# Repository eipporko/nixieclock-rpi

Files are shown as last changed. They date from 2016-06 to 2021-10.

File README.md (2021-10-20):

"Buy Me A Coffee" (https://www.buymeacoffee.com/eipporko)

6 digit Nixie Clock
===================

## Motivation

* [Alex's Nixie Clock](https://www.raspberrypi.org/blog/alexs-nixie-clock/)

## Project structure

 * `hardware/eagle` - PCB design and schematics
 * `hardware/docs`  - various PDF datasheets for components used
 * `software`       - clock program

## BOM Summary
Main components

 * IN-8-2 Nixie tubes
 * MH74141 Nixie driver
 * 74HCT259 8-bit addressable latch
 * SN74LS77 4-bit D latch
 * ULN2803A Eight Darligton array
 * Raspberry Pi Zero, 1, 2 or 3 (Models B, B+)

The BCD decoder IC and Nixie tubes is hard to obtain, so far they're only
available on ebay and most of them are NOS(new old stock)

Check the schematics for the rest of the passives

## Theory of operation

### Architecture
Every digit of the display is composed by a Nixie tube (IN-8-2) driven by a
decimal decoder designed for directly drive this kind of gas-filled cold-cathode
indicators (MH74141) which input is supplied by a 4-bit D Latch (SN74LS77).

Each latch is multiplexed, with one 3-line to 8-line demux with latch (74HCT259),
in order to share the 4 bit bus with all the drivers.

In this way it's only needed 8 bits to control the clock's display.

```
** RPI GPIO HEADER SCHEMATIC **
                            .___.
                   +3V3---1-|O O|--2--+5V
           (SDA)  GPIO2---3-|O O|--4--+5V
          (SCL1)  GPIO3---5-|O O|--6--_
     (GPIO_GLCK)  GPIO4---7-|O O|--8-----GPIO14 (TXD0)
                       _--9-|O.O|-10-----GPIO15 (RXD0)
     (GPIO_GEN0) GPIO17--11-|O O|-12-----GPIO18 (GPIO_GEN1)
     (GPIO_GEN2) GPIO27--13-|O O|-14--_
     (GPIO_GEN3) GPIO22--15-|O O|-16-----GPIO23 (GPIO_GEN4)
                   +3V3--17-|O O|-18-----GPIO24 (GPIO_GEN5)
      (SPI_MOSI) GPIO10--19-|O.O|-20--_
      (SPI_MOSO) GPIO9 --21-|O O|-22-----GPIO25 (GPIO_GEN6)
      (SPI_SCLK) GPIO11--23-|O O|-24-----GPIO8  (SPI_C0_N)
                       _-25-|O O|-26-----GPIO7  (SPI_C1_N)
        (EEPROM) ID_SD---27-|O O|-28-----ID_SC Reserved for ID EEPROM
                 GPIO5---29-|O.O|-30--_
                 GPIO6---31-|O O|-32-----GPIO12
                 GPIO13--33-|O O|-34--_
                 GPIO19--35-|O O|-36-----GPIO16
                 GPIO26--37-|O O|-38-----GPIO20
                       _-39-|O O|-40-----GPIO21
                            '---'

** NIXIE DIGIT MESSAGE **

                 DATA            ADDRESS    STRBE
           ,--------------,    ,---------,  ,---,
           A    B    C    D    A    B    C    |
           |    |    |    |    |    |    |    |
        | $22  $18  $16  $15  $13  $12  $11  $7 |
        '---------------------------------------'

```

## Installation

### Configuring GPIO
```
sudo raspi-config
```
###

### Build clock

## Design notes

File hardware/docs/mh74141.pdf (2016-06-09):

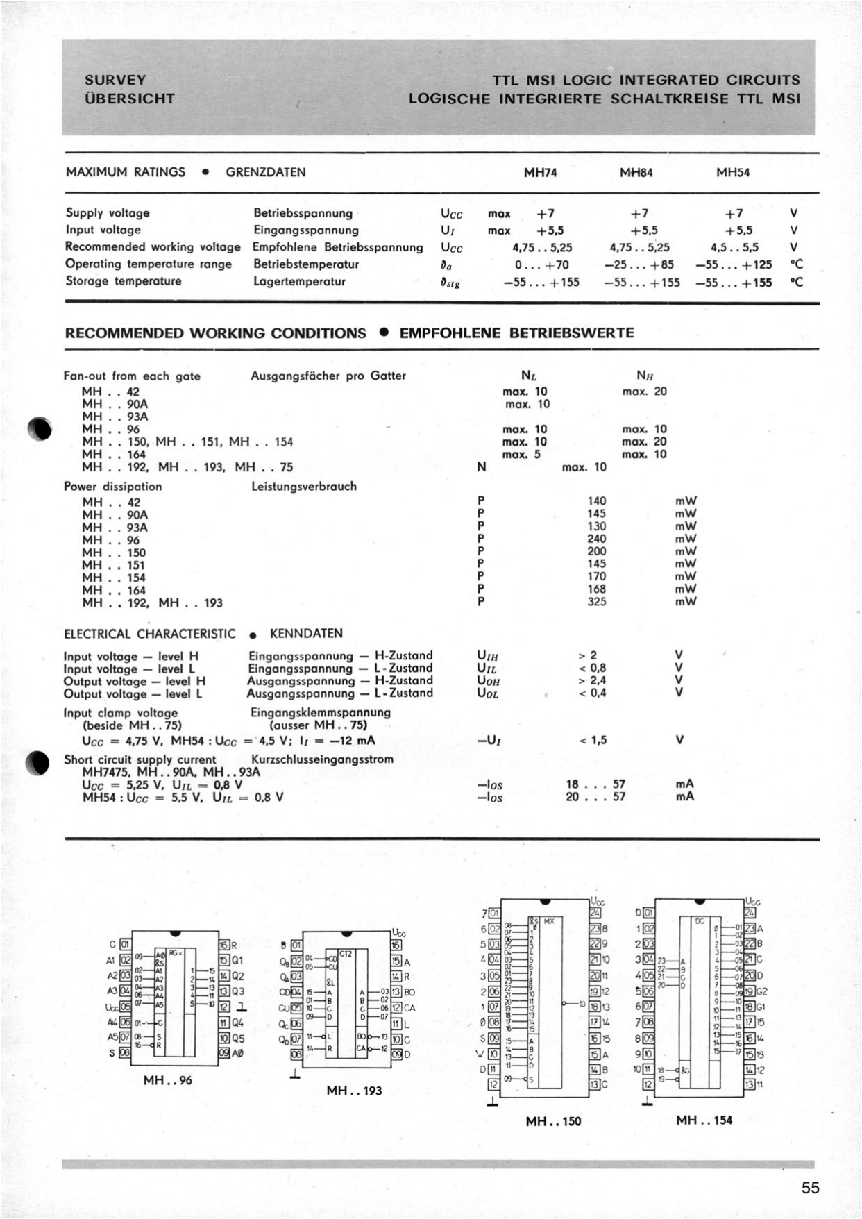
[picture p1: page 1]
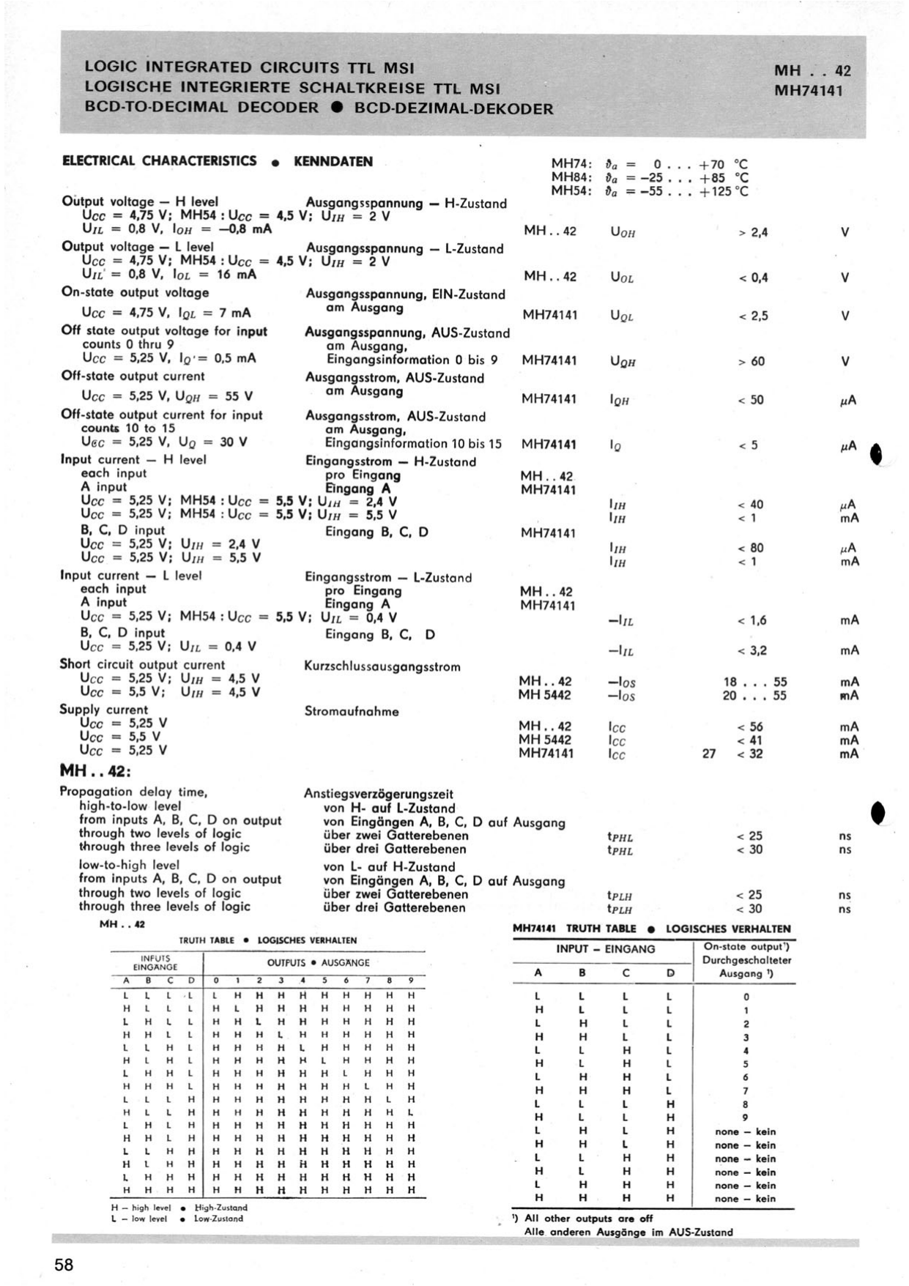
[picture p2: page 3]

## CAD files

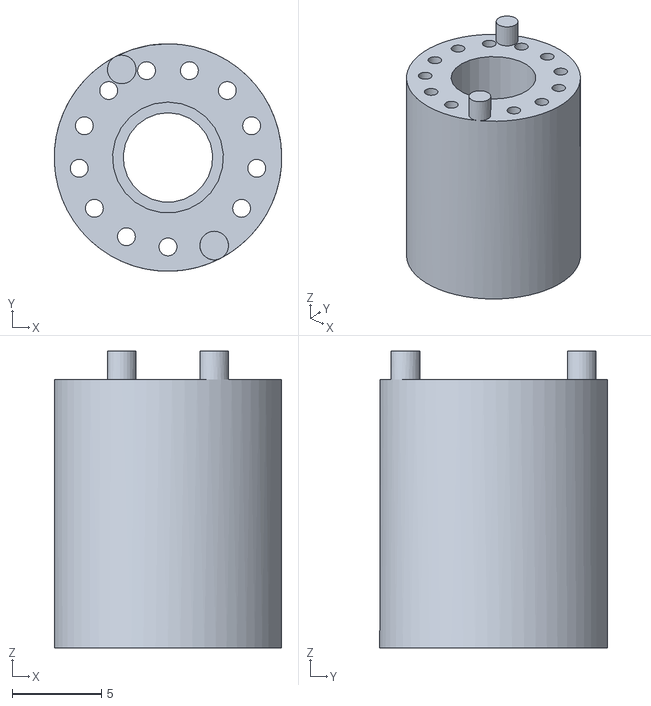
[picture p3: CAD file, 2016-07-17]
hardware/3dprint/in82socket.stl
12.7 x 12.7 x 16.6

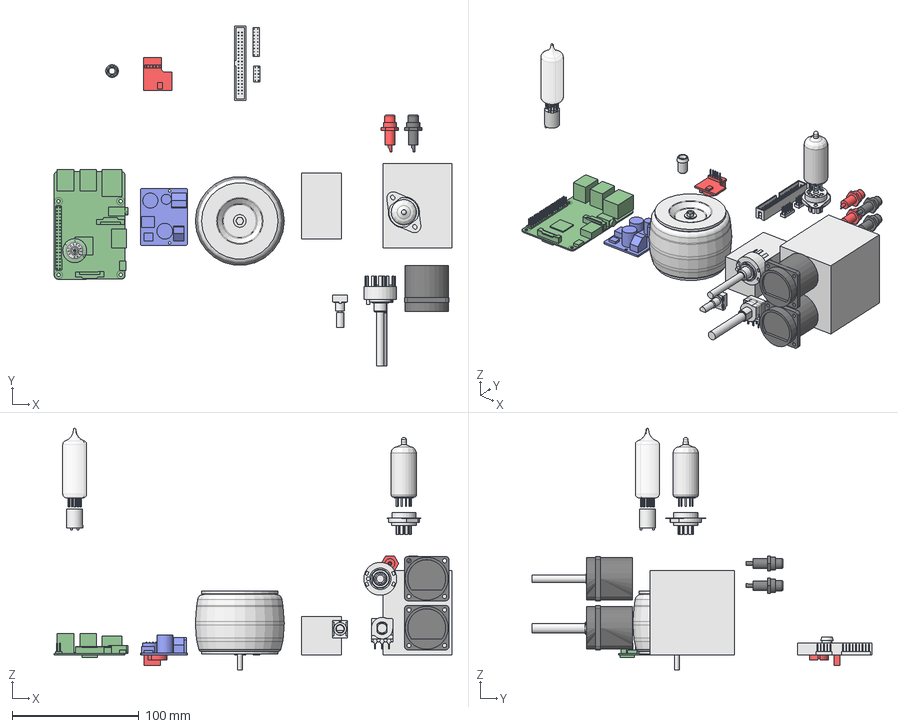
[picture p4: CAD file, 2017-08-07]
hardware/freecad/nixie-clock.fcstd
313.9 x 268.1 x 190.5 mm
Switch
Volume Potentiometer
ECC82_Socket
ECC82 Tube
VUmeter L
VUmeter R
Cubo
Cubo001
Input RCA Left
Input RCA Right
Output RCA Left
Output RCA Right
Tuerca + arandela001
Tapa001
Toroide001
Clone of Tapa001
Tornillo + arandela001
Nixie Tube
RaspberryPi
Power Supply
LED Trim
Nixie Tube Support
Rotary
Real Time Clock
raspberry pin header
header 2x9
header 2xfive

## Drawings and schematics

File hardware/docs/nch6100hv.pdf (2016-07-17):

NCH6100HV High Voltage Power Supply v1.0.0 | http://www.nixieclock.org
Designer: Yan Zeyuan. China. | Email:yanzeyuan@163.com | Website：www.nixieclock.org | 1 / 4

# NCH6100HV High Voltage DC Power Supply

Designer： | Yan Zeyuan | Version 1.0.0
Website： | http://www.nixieclock.org
E-mail： | yanzeyuan@163.com

# Attention

### ◇ Attention： High voltage circuit on the board, do not touch the circuit board and

| components if it’s working.
◇ Warning: | Overload prohibited (Input voltage/output current out of range).
◇ Warning: | Exposing outdoor prohibited, using in moist or raining place prohibited.
◇ Warning: | Board will generate heat, be sure the board is well heat dissipation.

# Features

### NCH6100HV high voltage power supply module is miniature step-up DC-DC converter with high

efficiency and low heat operating from 12 to 24VDC input, with an output of 85 to 235VDC set by a precise potentiometer. Designed for Nixie tube, VFD tube, Magic eye etc. Shutdown mode are controlled via SHDN logic input. PCB terminals and pin headers are optional.

# Technical specifications

### Electronic Specifications

Specification | Symbol | Min | Typ | Max | Units
Input voltage | VIN | 10.00 | 12.00 | 24.00 | Volts
Output voltage (Io = 10mA) | VOUT | 85.00 | --- | 235.00 | Volts
Output current (VIN = 12V VOUT = 90V) | IOUT | 0 | 45 | 95 | mAmps
Output current (VIN = 12V VOUT = 170V) | | 0 | 35 | 55 | mAmps
Output current (VIN = 12V VOUT = 220V) | | 0 | 24 | 35 | mAmps
SHDN input voltage | VSHDN | 1.2 | --- | VIN | Volts
SHDN input current | ISHDN | --- | --- | 2 | mAmps
Shutdown current (VIN = 12V VOUT = 170V) | IOFF | --- | 15 | --- | mAmps
Efficiency (VIN = 12-18VDC, 50%-80% rated load) | Efficiency | --- | 80 | --- | %

Notes:

1. Ground or float SHDN to enable switcher, must be tied to VIN to turn off switcher.
2. No input reverse polarity protection is provided.

Designer: Yan Zeyuan. China. | Email:yanzeyuan@163.com | Website：www.nixieclock.org | 2 / 4

### Efficiency curve ( VIN = DC 12V )

### Typical connection

95

90

85

80

75

70

Efficiency - %

0 | 40 | 60 | 80 | 100
Ouput current - mA

Vo = 90v

EFFICIENCY
vs
OUTPUT CURRENT

20

95

90

85

80

75

70

Efficiency - %

0 | 10 | 20 | 30 | 40 | 50 | 60 | 70
Ouput current - mA

Vo = 170v

EFFICIENCY
vs
OUTPUT CURRENT

95

90

85

80

75

70

Efficiency - %

0 | 10 | 20 | 30 | 40
Ouput current - mA

Vo = 220v

EFFICIENCY
vs
OUTPUT CURRENT

DC 12v - 24v IN

GND | GND

SHDN

VIN

GND

HV | DC 85v - 235v OUT

GND

NCH6100HV

DC 12v - 24v IN

GND | GND

SHDN
VIN

GND

HV | DC 85v - 235v OUT

GND

NCH6100HV

DC 12v - 24v IN

GND | GND

SHDN

VIN

GND

HV | OUT OFF

GND

NCH6100HV

DC 12v - 24v IN

GND | GND

SHDN
VIN

GND

HV | OUT ON/OFF

GND

NCH6100HV

I/O | MCU | GND | GND

Always on - float SHDN

ON with connect SHDN to GND

Off with connect SHDN to VIN

MCU control
SHDN High - Off
SHDN Low - On

Note:

### 1. Recommended input capacitor if the module is located far

from the power.

### 2. Module will generate heat, be sure the board is well heat

dissipation.

### Adjust output voltage

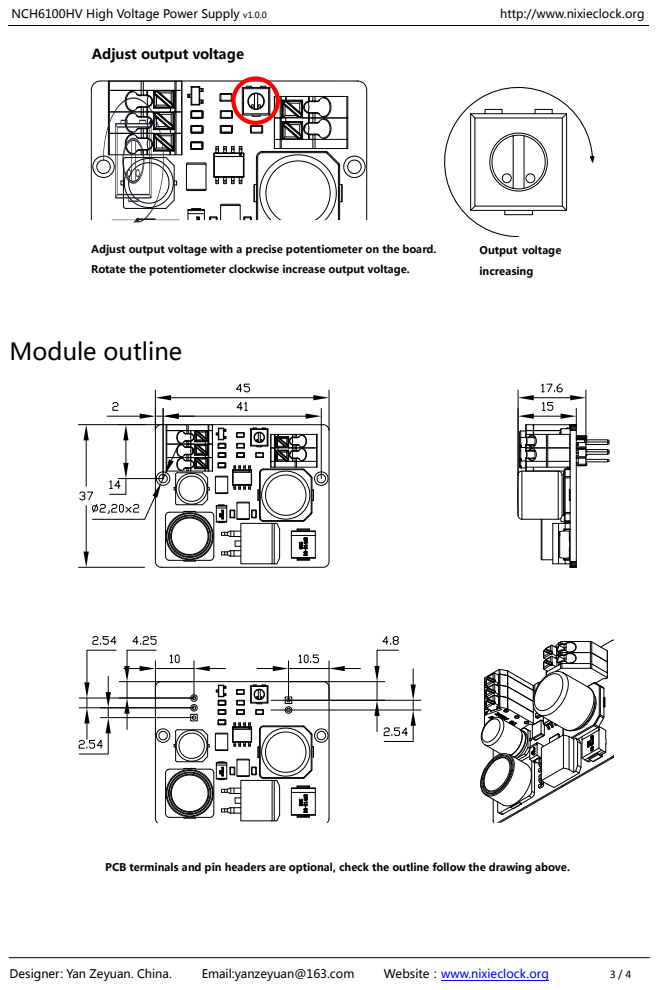
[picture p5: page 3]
Designer: Yan Zeyuan. China.; Email:yanzeyuan@163.com; Website：www.nixieclock.org; Module outline; Output voltage; increasing

Adjust output voltage with a precise potentiometer on the board.
Rotate the potentiometer clockwise increase output voltage.

PCB terminals and pin headers are optional, check the outline follow the drawing above.

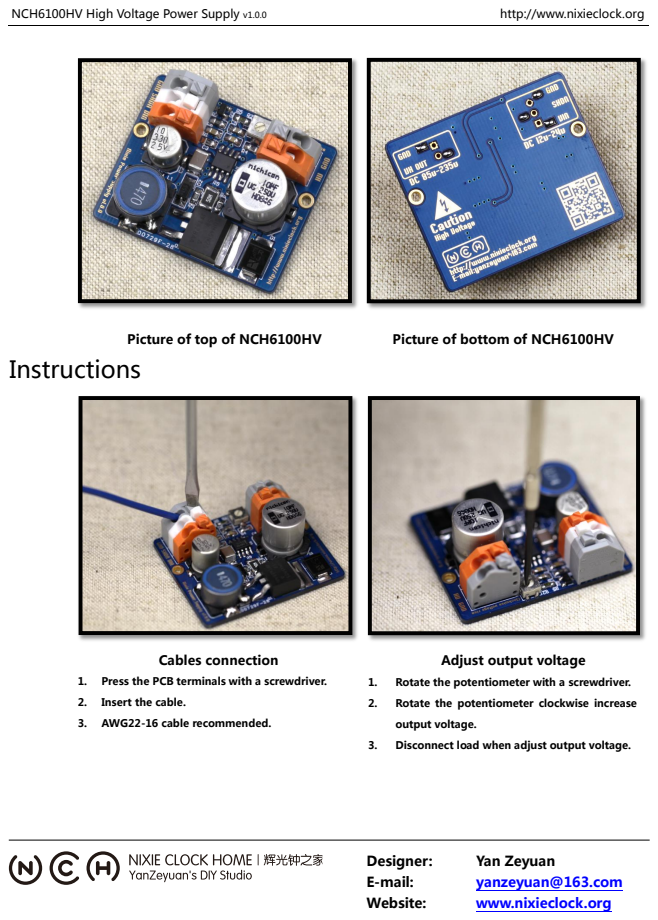
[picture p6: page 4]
Designer: Yan Zeyuan. China.; Email:yanzeyuan@163.com; Website：www.nixieclock.org; Picture of top of NCH6100HV; Picture of bottom of NCH6100HV; Instructions; Designer:; Yan Zeyuan; E-mail:; yanzeyuan@163.com; Website:; www.nixieclock.org; Cables connection

Adjust output voltage

1. Press the PCB terminals with a screwdriver.
2. Insert the cable.
3. AWG22-16 cable recommended.

1. Rotate the potentiometer with a screwdriver.
2. Rotate the potentiometer clockwise increase
output voltage.
3. Disconnect load when adjust output voltage.

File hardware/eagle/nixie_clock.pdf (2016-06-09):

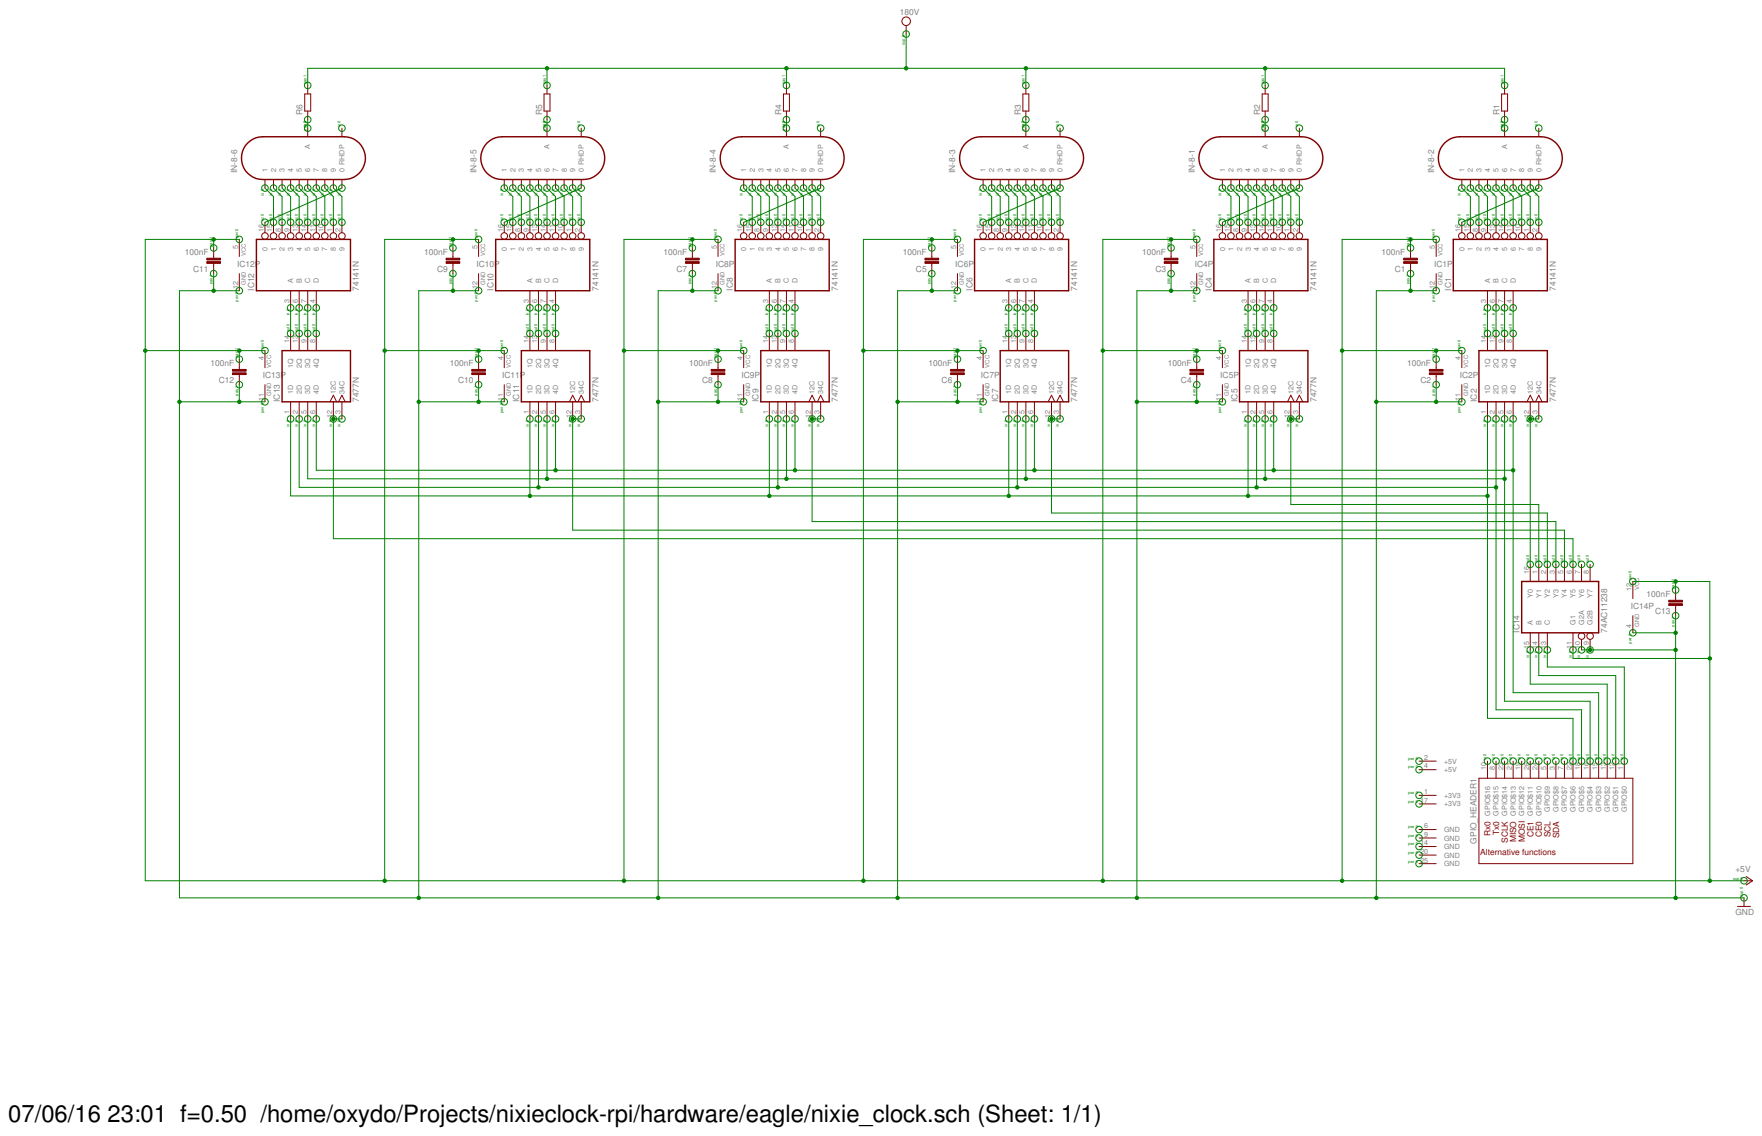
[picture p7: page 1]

07/06/16 23:01 f=0.50 /home/oxydo/Projects/nixieclock-rpi/hardware/eagle/nixie_clock.sch (Sheet: 1/1)

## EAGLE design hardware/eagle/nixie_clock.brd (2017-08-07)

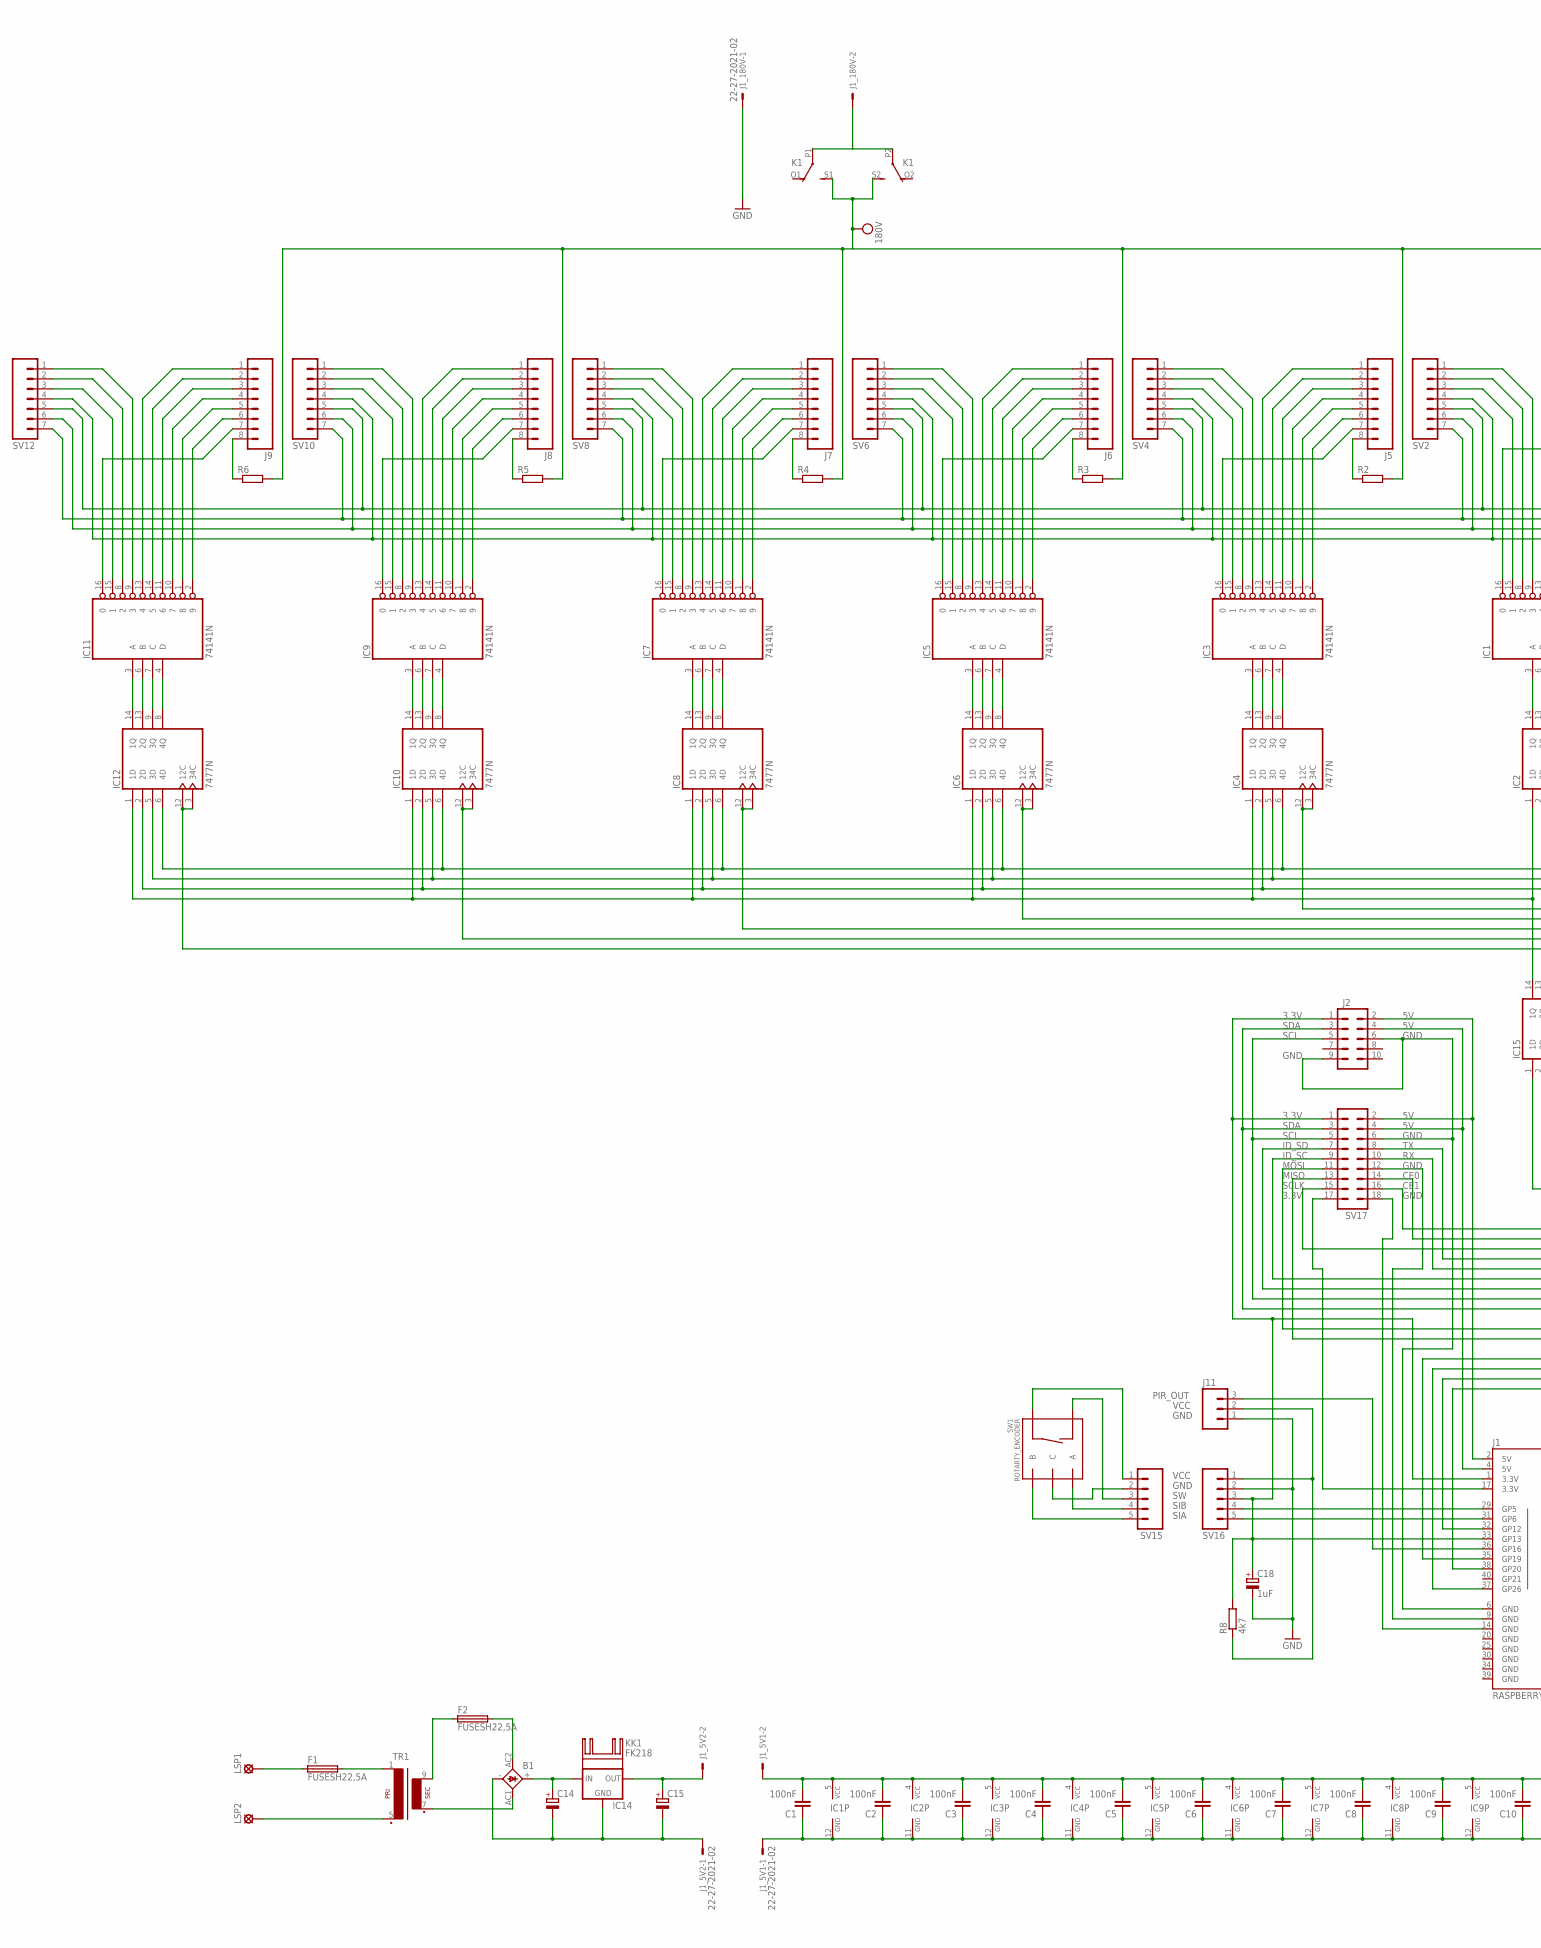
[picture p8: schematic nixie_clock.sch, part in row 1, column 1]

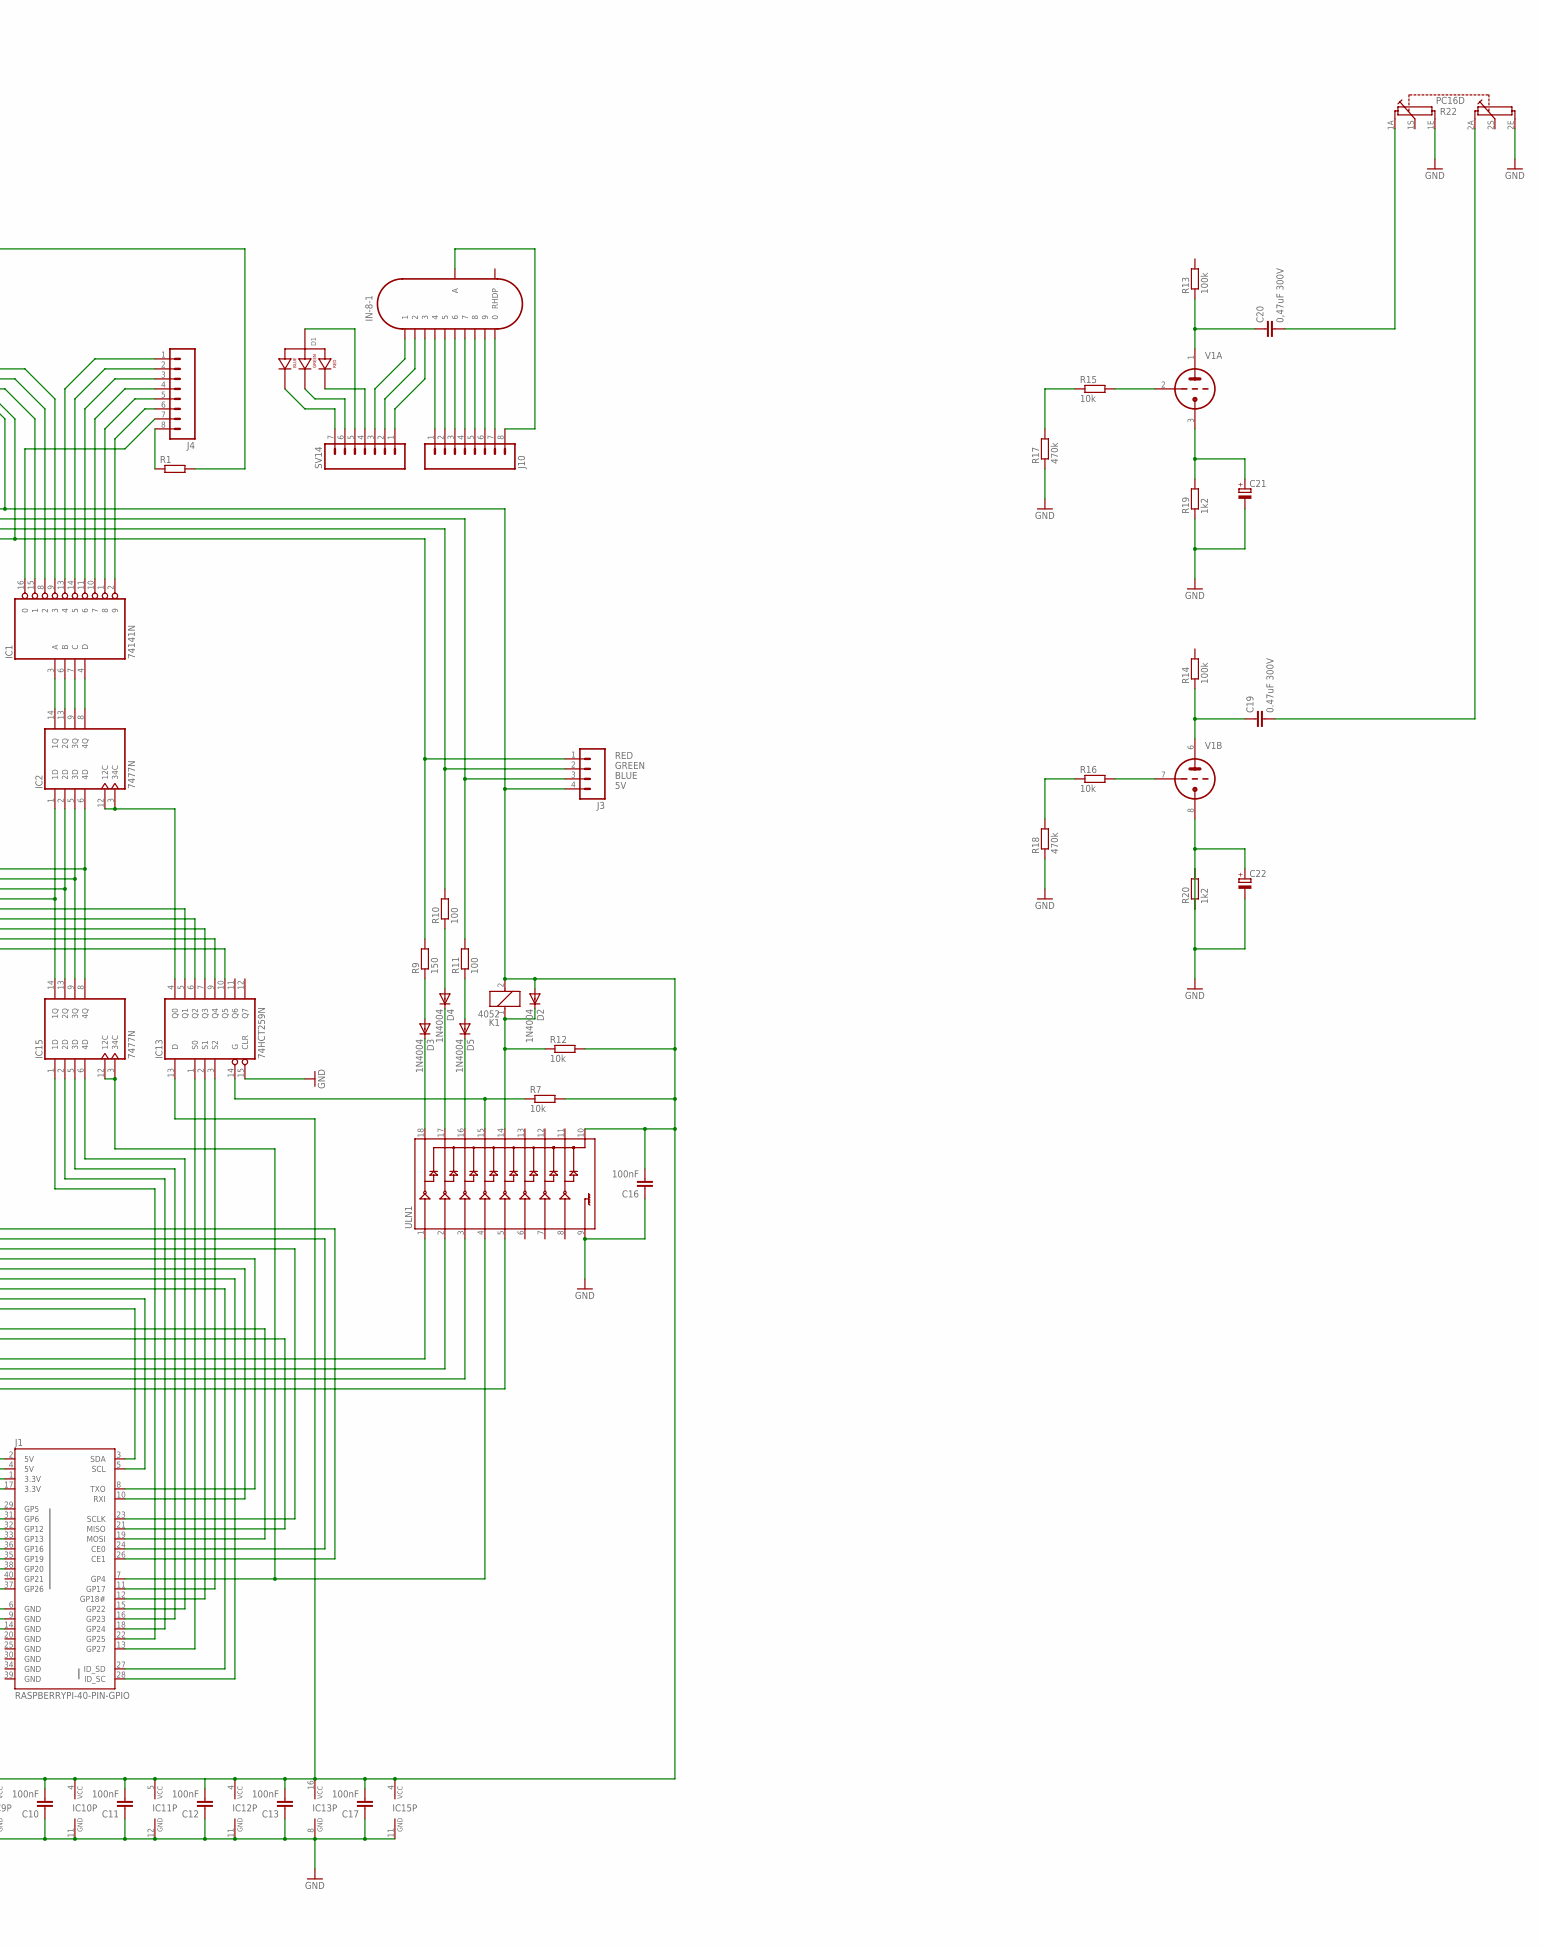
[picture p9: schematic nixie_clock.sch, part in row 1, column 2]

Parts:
B1: FBP1,5
C1, C2, C3, C4, C5, C6, C7, C8, C9, C10, C11, C12, C13, C16, C17: 100nF; C025-024X044; MPN MCFYU6104Z6
C14: CPOL-EUE5-10.5; E5-10,5
C15: CPOL-EUE3.5-10; E3,5-10
C18: 1uF; E2,5-5
C19: 0.47uF 300V; C275-154X316
C20: 0,47uF 300V; C275-154X316
C21, C22: CPOL-EUE2.5-5; E2,5-5
D1: LED-RGB-CA-THRUCLEAR; LED-RGB-THRU
D2, D3, D4, D5: 1N4004; DO41-10
F1, F2: FUSESH22,5A; SH22,5A
IC1, IC3, IC5, IC7, IC9, IC11: 74141N; DIL16
IC2, IC4, IC6, IC8, IC10, IC12, IC15: 7477N; DIL14
IC13: 74HCT259N; DIL16
IC14: 78XXS
IN-8-1: IN-8-2
J1: RASPBERRYPI-40-PIN-GPIO; 2X20-SHROUDED
J1_5V1, J1_5V2, J1_180V: 22-27-2021-02; 6410-02
J2: M05X2PTH; AVR_ICSP
J3: M04; 04P
J4, J5, J6, J7, J8, J9, J10: M08; 1X08_ROUND
J11: M03; 03P
K1: 4052; F4052
KK1: FK218
LSP1, LSP2: LSP10
R1, R2, R3, R4, R5, R6: R-EU_0207/15; 0207/15; MPN MMA02040E5101BB100
R7, R12: 10k; 0204/7
R8: 4k7; 0204/7
R9: 150; 0204/7
R10, R11: 100; 0204/7
R13, R14: 100k; 0309/10
R15, R16: 10k; 0309/10
R17, R18: 470k; 0309/10
R19, R20: 1k2; 0309/10
R22: PC16D
SV2, SV4, SV6, SV8, SV10, SV12, SV14: M07; 1X07
SV15: M05PTH; 1X05
SV16: M05; 05P
SV17: MA09-2
SW1: ROTARTY_ENCODER; ROTARY_ENC_PLAIN
TR1: EI42-1
ULN1: ULN2803DIP; DIL18
V1: ECC82-P; NOVAL

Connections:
5V: C1.2, C2.2, C3.2, C4.2, C5.2, C6.2, C7.2, C8.2, C9.2, C10.2, C11.2, C12.2, C13.2, C16.2, C17.2, D2.A, IC1.5 (VCC), IC2.4 (VCC), IC3.5 (VCC), IC4.4 (VCC), IC5.5 (VCC), IC6.4 (VCC), IC7.5 (VCC), IC8.4 (VCC), IC9.5 (VCC), IC10.4 (VCC), IC11.5 (VCC), IC12.4 (VCC), IC13.13 (D), IC13.16 (VCC), IC15.4 (VCC), J1_5V1.2, J3.4, K1.2, R7.2, R12.2, SV2.5, SV4.5, SV6.5, SV8.5, SV10.5, SV12.5, ULN1.10
BLUE: J3.3, R11.2, SV2.7, SV4.7, SV6.7, SV8.7, SV10.7, SV12.7
GND: C1.1, C2.1, C3.1, C4.1, C5.1, C6.1, C7.1, C8.1, C9.1, C10.1, C11.1, C12.1, C13.1, C16.1, C17.1, C18.-, C21.-, IC1.12 (GND), IC2.11 (GND), IC3.12 (GND), IC4.11 (GND), IC5.12 (GND), IC6.11 (GND), IC7.12 (GND), IC8.11 (GND), IC9.12 (GND), IC10.11 (GND), IC11.12 (GND), IC12.11 (GND), IC13.8 (GND), IC13.15 (CLR), IC15.11 (GND), J1.20 (GND), J1.25 (GND), J1.30 (GND), J1.34 (GND), J1.39 (GND), J1_5V1.1, J1_180V.1, J11.1, R17.1, R18.1, R19.1, R22.1E, R22.2E, SV16.2, ULN1.9
GREEN: J3.2, R10.2, SV2.6, SV4.6, SV6.6, SV8.6, SV10.6, SV12.6
unnamed: IN-8-1.4, J10.1
unnamed: IC1.3 (A), IC2.14 (1Q)
unnamed: IC1.6 (B), IC2.13 (2Q)
unnamed: IC1.7 (C), IC2.9 (3Q)
unnamed: IC1.4 (D), IC2.8 (4Q)
unnamed: IN-8-1.5, J10.2
unnamed: IN-8-1.6, J10.3
unnamed: IN-8-1.7, J10.4
unnamed: IN-8-1.8, J10.5
unnamed: IN-8-1.9, J10.6
unnamed: IN-8-1.0, J10.7
unnamed: IN-8-1.3, SV14.1
unnamed: IN-8-1.2, SV14.2
unnamed: IN-8-1.1, SV14.3
unnamed: D1.1 (RED_CATHODE), SV14.4
unnamed: IC2.3 (34C), IC2.12 (12C), IC13.4 (Q0)
unnamed: IC2.6 (4D), IC4.6 (4D), IC6.6 (4D), IC8.6 (4D), IC10.6 (4D), IC12.6 (4D), IC15.8 (4Q)
unnamed: IC1.13 (4), J4.1
unnamed: IC1.14 (5), J4.2
unnamed: D1.4 (BLUE_CATHODE), SV14.7
unnamed: D1.2 (ANODE), SV14.5
unnamed: D1.3 (GREEN_CATHODE), SV14.6
unnamed: IC1.11 (6), J4.3
unnamed: IC1.10 (7), J4.4
unnamed: IC1.1 (8), J4.5
unnamed: IC1.2 (9), J4.6
unnamed: IC1.9 (3), SV2.1
unnamed: IC1.8 (2), SV2.2
unnamed: IC3.3 (A), IC4.14 (1Q)
unnamed: IC3.6 (B), IC4.13 (2Q)
unnamed: IC3.7 (C), IC4.9 (3Q)
unnamed: IC3.4 (D), IC4.8 (4Q)
unnamed: IC4.3 (34C), IC4.12 (12C), IC13.5 (Q1)
unnamed: IC1.15 (1), SV2.3
unnamed: IC1.16 (0), J4.7
unnamed: IC3.13 (4), J5.1
unnamed: IC3.14 (5), J5.2
unnamed: IC3.11 (6), J5.3
unnamed: IC3.10 (7), J5.4
unnamed: IC3.1 (8), J5.5
unnamed: IC3.2 (9), J5.6
unnamed: IC3.16 (0), J5.7
unnamed: IC3.9 (3), SV4.1
unnamed: IC5.3 (A), IC6.14 (1Q)
unnamed: IC5.6 (B), IC6.13 (2Q)
unnamed: IC5.7 (C), IC6.9 (3Q)
unnamed: IC5.4 (D), IC6.8 (4Q)
unnamed: IC6.3 (34C), IC6.12 (12C), IC13.6 (Q2)
unnamed: IC3.8 (2), SV4.2
unnamed: IC3.15 (1), SV4.3
unnamed: IC5.13 (4), J6.1
unnamed: IC5.14 (5), J6.2
unnamed: IC5.11 (6), J6.3
unnamed: IC5.10 (7), J6.4
unnamed: IC5.1 (8), J6.5
unnamed: IC5.2 (9), J6.6
unnamed: IC5.16 (0), J6.7
unnamed: IC5.9 (3), SV6.1
unnamed: IC7.3 (A), IC8.14 (1Q)
unnamed: IC7.6 (B), IC8.13 (2Q)
unnamed: IC7.7 (C), IC8.9 (3Q)
unnamed: IC7.4 (D), IC8.8 (4Q)
unnamed: IC8.3 (34C), IC8.12 (12C), IC13.7 (Q3)
unnamed: IC5.8 (2), SV6.2
unnamed: IC5.15 (1), SV6.3
unnamed: IC7.13 (4), J7.1
unnamed: IC7.14 (5), J7.2
unnamed: IC7.11 (6), J7.3
unnamed: IC7.10 (7), J7.4
unnamed: IC7.1 (8), J7.5
unnamed: IC7.2 (9), J7.6
unnamed: IC7.16 (0), J7.7
unnamed: IC7.9 (3), SV8.1
unnamed: IC9.3 (A), IC10.14 (1Q)
unnamed: IC9.6 (B), IC10.13 (2Q)
unnamed: IC9.7 (C), IC10.9 (3Q)
unnamed: IC9.4 (D), IC10.8 (4Q)
unnamed: IC10.3 (34C), IC10.12 (12C), IC13.9 (Q4)
unnamed: IC7.8 (2), SV8.2
unnamed: IC7.15 (1), SV8.3
unnamed: IC9.13 (4), J8.1
unnamed: IC9.14 (5), J8.2
unnamed: IC9.11 (6), J8.3
unnamed: IC9.10 (7), J8.4
unnamed: IC9.1 (8), J8.5
unnamed: IC9.2 (9), J8.6
unnamed: IC11.13 (4), J9.1
unnamed: IC11.14 (5), J9.2
unnamed: IC11.3 (A), IC12.14 (1Q)
unnamed: IC11.6 (B), IC12.13 (2Q)
unnamed: IC11.7 (C), IC12.9 (3Q)
unnamed: IC11.4 (D), IC12.8 (4Q)
unnamed: IC12.3 (34C), IC12.12 (12C), IC13.10 (Q5)
unnamed: IC2.5 (3D), IC4.5 (3D), IC6.5 (3D), IC8.5 (3D), IC10.5 (3D), IC12.5 (3D), IC15.9 (3Q)
unnamed: IC2.2 (2D), IC4.2 (2D), IC6.2 (2D), IC8.2 (2D), IC10.2 (2D), IC12.2 (2D), IC15.13 (2Q)
unnamed: IC2.1 (1D), IC4.1 (1D), IC6.1 (1D), IC8.1 (1D), IC10.1 (1D), IC12.1 (1D), IC15.14 (1Q)
unnamed: IC13.1 (S0), J1.13 (GP27)
unnamed: IC13.2 (S1), J1.12 (GP18#)
unnamed: IC13.3 (S2), J1.11 (GP17)
unnamed: IC9.16 (0), J8.7
unnamed: IC9.9 (3), SV10.1
unnamed: IC9.8 (2), SV10.2
unnamed: IC9.15 (1), SV10.3
unnamed: IN-8-1.A, J10.8
unnamed: IC11.11 (6), J9.3
unnamed: IC11.10 (7), J9.4
unnamed: IC11.1 (8), J9.5
unnamed: B1.+, C14.+, IC14.IN
unnamed: IC11.2 (9), J9.6
unnamed: IC11.16 (0), J9.7
unnamed: IC11.9 (3), SV12.1
unnamed: IC11.8 (2), SV12.2
unnamed: IC11.15 (1), SV12.3
unnamed: J8.8, R5.1
unnamed: J9.8, R6.1
unnamed: D4.C, ULN1.17
unnamed: F1.1, LSP1.MP
unnamed: F1.2, TR1.1
unnamed: LSP2.MP, TR1.5 (P2)
unnamed: F2.1, TR1.9 (S4)
unnamed: B1.AC2 (AC1), F2.2
unnamed: B1.AC1 (AC2), TR1.7 (S3)
unnamed: C15.+, IC14.OUT, J1_5V2.2
unnamed: J1.35 (GP19), ULN1.1
unnamed: B1.-, C14.-, C15.-, IC14.GND, J1_5V2.1
unnamed: J1_180V.2, K1.P1, K1.P2
unnamed: J1.37 (GP26), ULN1.2
unnamed: SV15.4, SW1.A
unnamed: J1.32 (GP12), ULN1.3
unnamed: C18.+, J1.1 (3.3V), J1.33 (GP13), J2.1, R8.2, SV16.3, SV17.1
unnamed: SV15.3, SW1.SW-
unnamed: SV15.1, SW1.SW+
unnamed: SV15.2, SW1.C
unnamed: SV15.5, SW1.B
unnamed: D3.C, ULN1.18
unnamed: D5.C, ULN1.16
unnamed: J1.31 (GP6), SV16.5
unnamed: J1.29 (GP5), SV16.4
unnamed: D3.A, R9.1
unnamed: IC13.14 (G), R7.1, ULN1.15
unnamed: IC15.1 (1D), J1.22 (GP25)
unnamed: IC15.2 (2D), J1.18 (GP24)
unnamed: IC15.5 (3D), J1.16 (GP23)
unnamed: IC15.6 (4D), J1.15 (GP22)
unnamed: IC15.3 (34C), IC15.12 (12C), J1.7 (GP4), ULN1.4
unnamed: D4.A, R10.1
unnamed: D5.A, R11.1
unnamed: J1.38 (GP20), ULN1.5
unnamed: J7.8, R4.1
unnamed: D2.C, K1.1, R12.1, ULN1.14
unnamed: J1.17 (3.3V), SV17.17
unnamed: J1.4 (5V), J2.4, SV17.4
unnamed: J1.3 (SDA), J2.3, SV17.3
unnamed: J1.5 (SCL), J2.5, SV17.5
unnamed: J1.6 (GND), J2.6, J2.9, SV17.6
unnamed: J1.27 (ID_SD), SV17.7
unnamed: J1.28 (ID_SC), SV17.9
unnamed: J1.8 (TXO), SV17.8
unnamed: J1.10 (RXI), SV17.10
unnamed: J1.19 (MOSI), SV17.11
unnamed: J1.21 (MISO), SV17.13
unnamed: J1.23 (SCLK), SV17.15
unnamed: J4.8, R1.1
unnamed: J1.9 (GND), SV17.12
unnamed: J1.24 (CE0), SV17.14
unnamed: J1.26 (CE1), SV17.16
unnamed: J1.14 (GND), SV17.18
unnamed: J6.8, R3.1
unnamed: R1.2, R2.2, R3.2, R4.2, R5.2, R6.2
unnamed: J5.8, R2.1
unnamed: J1.2 (5V), J2.2, SV17.2
unnamed: J1.36 (GP16), J11.3
unnamed: R15.1, R17.2
unnamed: R16.1, R18.2
unnamed: R15.2, V1.2 (TG)
unnamed: C20.1, R13.1, V1.1 (TA)
unnamed: C19.1, R14.1, V1.6 (TA)
unnamed: R16.2, V1.7 (TG)
unnamed: C22.+, C22.-, R20.1, R20.2, V1.8 (TK)
unnamed: C21.+, R19.2, V1.3 (TK)
unnamed: J11.2, R8.1, SV16.1
unnamed: C20.2, R22.1A
unnamed: C19.2, R22.2A
RED: J3.1, R9.2, SV2.4, SV4.4, SV6.4, SV8.4, SV10.4, SV12.4
VCC: K1.S1 (S), K1.S2 (S)

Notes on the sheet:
SIA
SIB
GND
VCC
3.3V
SDA
SCL
ID_SD
ID_SC
MOSI
MISO
SCLK
CE0
CE1
PIR_OUT

Board: 2 copper layers, 99 parts (4 on the bottom side), 189 nets, no tracks yet.

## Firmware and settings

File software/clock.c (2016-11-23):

#include <stdio.h>
#include <string.h>
#include <errno.h>
#include <stdlib.h>
#include <time.h>
#include <math.h>

#include <wiringPi.h>
#include <softPwm.h>
#include <pthread.h>

/***********************************************************
*  CONSTANTS
***********************************************************/
#define  ADDR_C_PIN         0
#define  ADDR_B_PIN         1
#define  ADDR_A_PIN         2
#define  DATA_D_PIN	        3
#define  DATA_C_PIN         4
#define  DATA_B_PIN         5
#define  DATA_A_PIN         6
#define  STROBE_PIN         7

#define  ROTARY_A_PIN       21
#define  ROTARY_B_PIN       22
#define  ROTARY_SW_PIN      23

#define  LED_RED_PIN        24
#define  LED_GREEN_PIN      25
#define  LED_BLUE_PIN       26

#define  PIR_PIN            27
#define  RELAY_PIN          28
#define  AUTO_PIN           29

#define  BLINK_IN_DELAY     400
#define  BLINK_OUT_DELAY    200
#define  COUNTDOWN_TIMER    3600000


/***********************************************************
*  GLOBAL VARIABLES
***********************************************************/
//Rotary Encoder
static volatile int globalCounter = 0 ;
volatile int lastEncoded;
unsigned char MSB;
unsigned char LSB;
int rencoderEnabled = 0;
pthread_mutex_t mutex = PTHREAD_MUTEX_INITIALIZER;
int rencoderUpdated = 0;

//Relay Countdown Timer
pthread_mutex_t lockCountdown = PTHREAD_MUTEX_INITIALIZER;
pthread_cond_t condCountdown = PTHREAD_COND_INITIALIZER;
int countdownTimer = 0;

//RGB Led
pthread_mutex_t lockRGBLed = PTHREAD_MUTEX_INITIALIZER;
pthread_cond_t condRGBLed = PTHREAD_COND_INITIALIZER;
int fadeMap[3][3] = { {LED_RED_PIN, LED_GREEN_PIN, -1},
                      {-1, LED_GREEN_PIN, LED_BLUE_PIN},
                      {LED_RED_PIN, -1, LED_BLUE_PIN} };


/***********************************************************
*  TIME FUNCTIONS
***********************************************************/
static long timeSpecToMillis(struct timespec* ts)
{
  return round( (double)ts->tv_sec * 1000 + (double)ts->tv_nsec / 1000000.0 );
}


/***********************************************************
*  MATHEMATIC FUNCTIONS
***********************************************************/
int mod(int a, int b) {
  int r = a % b;
  return r < 0 ? r + b : r;
}


/***********************************************************
*  PIR & RELAY FUNCTIONS
***********************************************************/
void pirISR(void)
{
  if ( digitalRead(PIR_PIN) == HIGH ) {
    digitalWrite(RELAY_PIN, HIGH);
    pthread_mutex_lock(&lockCountdown);
    countdownTimer = COUNTDOWN_TIMER;
    pthread_cond_signal(&condCountdown);
    pthread_mutex_unlock(&lockCountdown);
  }
}

PI_THREAD (relayCountdownTimer) {
    while(1) {
        delay(100);
        pthread_mutex_lock(&lockCountdown);
        countdownTimer -= 100;
        pthread_mutex_unlock(&lockCountdown);
        if (countdownTimer <= 0) {
            digitalWrite(RELAY_PIN, LOW);
            pthread_mutex_lock(&lockCountdown);
            while(countdownTimer <= 0) pthread_cond_wait(&condCountdown, &lockCountdown);
            pthread_mutex_unlock(&lockCountdown);
        }

    }
}


/***********************************************************
*  ROTARY ENCODER & RGB LED FUNCTIONS
***********************************************************/
void btnISR(void)
{
  pthread_mutex_lock(&lockRGBLed);

  rencoderEnabled = (rencoderEnabled == 0);
  if (rencoderEnabled)
      pthread_cond_signal(&condRGBLed);

  pthread_mutex_unlock(&lockRGBLed);
}

void updateEncoder() {
  if (rencoderEnabled) {
    int MSB = digitalRead(ROTARY_A_PIN);
    int LSB = digitalRead(ROTARY_B_PIN);

    int encoded = (MSB << 1) | LSB;
    int sum = (lastEncoded << 2) | encoded;

    if(sum == 0b1101 || sum == 0b0100 || sum == 0b0010 || sum == 0b1011)
      globalCounter = mod(++globalCounter, 300);
    if(sum == 0b1110 || sum == 0b0111 || sum == 0b0001 || sum == 0b1000)
      globalCounter = mod(--globalCounter, 300);

    lastEncoded = encoded;

    pthread_mutex_lock(&mutex);
    rencoderUpdated = 1;
    pthread_mutex_unlock(&mutex);
  }
}

PI_THREAD (rgbLED) {

  int blinkIn = 1;
  int counter = globalCounter;
  int pos = counter/100;
  int channelDecrease = fadeMap[pos][pos];
  int channelIncrease = fadeMap[pos][mod(pos+1,3)];

  struct timespec timestamp, now;
  clock_gettime(CLOCK_MONOTONIC, &timestamp);

  while (1) {

    if (rencoderEnabled) {

      if (blinkIn) {
        if (rencoderUpdated) {
          counter = globalCounter;
          pos = counter/100;
          channelDecrease = fadeMap[pos][pos];
          channelIncrease = fadeMap[pos][mod(pos+1,3)];

          softPwmWrite(channelIncrease, mod(counter, 100));
          softPwmWrite(channelDecrease, 100 - mod(counter, 100));

          pthread_mutex_lock(&mutex);
          rencoderUpdated = 0;
          pthread_mutex_unlock(&mutex);
        }
        delay(10);
      }
      else {
        softPwmWrite(LED_RED_PIN, LOW);
        softPwmWrite(LED_GREEN_PIN, LOW);
        softPwmWrite(LED_BLUE_PIN, LOW);
        delay(10);

        pthread_mutex_lock(&mutex);
        rencoderUpdated = 1;
        pthread_mutex_unlock(&mutex);
      }

      clock_gettime(CLOCK_MONOTONIC, &now);
      long t = timeSpecToMillis(&now) - timeSpecToMillis(&timestamp);
      if ((blinkIn && t > BLINK_IN_DELAY) || (!blinkIn && t > BLINK_OUT_DELAY))
      {
        blinkIn = (blinkIn == 0);
        clock_gettime(CLOCK_MONOTONIC, &timestamp);
      }

    }
    else {

      softPwmWrite(channelIncrease, mod(counter, 100));
      softPwmWrite(channelDecrease, 100 - mod(counter, 100));

      pthread_mutex_lock(&lockRGBLed);
      while(!rencoderEnabled) pthread_cond_wait(&condRGBLed, &lockRGBLed);
      pthread_mutex_unlock(&lockRGBLed);
    }


  }
}


/***********************************************************
*  NIXIE CLOCK FUNCTIONS
***********************************************************/
void nixiePin(int pin, int value){
  if (pin != -1) {
    digitalWrite(pin, value);
  }
}

void nixiePins(int value, int address){

  nixiePin(ADDR_A_PIN, address&1);
  nixiePin(ADDR_B_PIN, address&2);
  nixiePin(ADDR_C_PIN, address&4);

  nixiePin(DATA_A_PIN, value&1);
  nixiePin(DATA_B_PIN, value&2);
  nixiePin(DATA_C_PIN, value&4);
  nixiePin(DATA_D_PIN, value&8);

  digitalWrite(STROBE_PIN, HIGH);

  delay (1);

  digitalWrite(STROBE_PIN, LOW);

  delay (11);
  //~=85 Hz
}

void testClock() {
  int digit = 0;
  int address = 0;
  for (digit = 0; digit < 10; digit++) {
    for (address = 0; address < 6; address++)
    nixiePins(digit, address);

    delay(250);
  }
}


/***********************************************************
*  SETUP FUNCTIONS
***********************************************************/
void initWiringPi() {

  if(wiringPiSetup() < 0){
		fprintf(stderr, "Unable to setup wiringPi:%s\n",strerror(errno));
		exit(1);
	}

  int i = 0;
  for (i = 0; i < 8; i++) {
    pinMode(i, OUTPUT);
    digitalWrite(i, LOW);
  }

  pinMode(RELAY_PIN, OUTPUT);
  digitalWrite(RELAY_PIN, LOW);

  pinMode(PIR_PIN, INPUT);
  pinMode(ROTARY_SW_PIN, INPUT);
  pinMode(ROTARY_A_PIN, INPUT);
  pinMode(ROTARY_B_PIN, INPUT);

  softPwmCreate (LED_RED_PIN, 0, 100);
  softPwmCreate (LED_GREEN_PIN, 0, 100);
  softPwmCreate (LED_BLUE_PIN, 0, 100);

  pullUpDnControl(ROTARY_SW_PIN, PUD_UP);

  if(wiringPiISR(ROTARY_SW_PIN, INT_EDGE_FALLING, &btnISR) < 0){
    fprintf(stderr, "Unable to init ISR\n");
    exit(1);
  }

  if(wiringPiISR(ROTARY_A_PIN, INT_EDGE_BOTH, &updateEncoder) < 0){
    fprintf(stderr, "Unable to init ISR\n");
    exit(1);
  }

  if(wiringPiISR(ROTARY_B_PIN,INT_EDGE_BOTH, &updateEncoder) < 0){
    fprintf(stderr, "Unable to init ISR\n");
    exit(1);
  }

  pullUpDnControl(PIR_PIN, PUD_UP);

  if(wiringPiISR(PIR_PIN, INT_EDGE_BOTH, &pirISR) < 0){
    fprintf(stderr, "Unable to init ISR\n");
    exit(1);
  }

  if (piThreadCreate(relayCountdownTimer) != 0) {
    printf("Thread didn't start - countdownTimer");
    exit(1);
  }

  if (piThreadCreate(rgbLED) != 0) {
    printf("Thread didn't start - rgbLED");
    exit(1);
  }

}

int main ()
{
  time_t now;
  struct timespec start, end;

  struct tm * ntm;

  initWiringPi();

  testClock();

  while(1) {
    clock_gettime(CLOCK_MONOTONIC, &start);
    time (&now);
    ntm = localtime (&now);
    printf ("%d : %d : %d \n", ntm->tm_hour, ntm->tm_min, ntm->tm_sec);

    nixiePins(ntm->tm_hour/10, 5);
    nixiePins(ntm->tm_hour%10, 4);
    nixiePins(ntm->tm_min/10, 3);
    nixiePins(ntm->tm_min%10, 2);
    nixiePins(ntm->tm_sec/10, 1);
    nixiePins(ntm->tm_sec%10, 0);

    clock_gettime(CLOCK_MONOTONIC, &end);
    int duration = timeSpecToMillis(&end) - timeSpecToMillis(&start);
    int tdelay = 1000 - duration;
    if (tdelay > 0)
      delay(tdelay);
  }

  pthread_cond_destroy(&condRGBLed);
  pthread_mutex_destroy(&lockRGBLed);
  pthread_cond_destroy(&condCountdown);
  pthread_mutex_destroy(&lockCountdown);
  pthread_mutex_destroy(&mutex);
  return 0;
}

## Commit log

2016-06-10 First test with wiringPi
2016-06-12 Added nixie tubes testing
2016-06-13 First board
    [nixie_clock.brd, nixie_clock.sch]
2016-06-14 Updated eagle project
    [nixie_clock.brd, nixie_clock.sch]
2016-06-15 External nixie tubes design
    [nixie_clock.brd, nixie_clock.sch]
2016-06-18 Added power supply on eagle project
    [nixie_clock.brd, nixie_clock.sch]
2016-06-19 FreeCad nixie model
    [nixie-clock.fcstd, nixie_clock.brd, nixie_clock.sch]
2016-06-23 Added relay
    [nixie_clock.brd, nixie_clock.sch]
2016-06-26 Added rotary encoder example
    [nixie_clock.brd, nixie_clock.sch]
2016-06-26 Update project
    [nixie_clock.brd, nixie_clock.sch]
2016-06-30 RGB led fading with rotary encoder
    [nixie_clock.brd, nixie_clock.sch]
2016-07-03 Working on Sunday
    [nixie-clock.fcstd, nixie_clock.brd, nixie_clock.sch]
2016-07-04 Added uln documentation
    [nixie-clock.fcstd, nixie_clock.brd, nixie_clock.sch]
2016-07-06 Added a Toroidal transformer
    [nixie-clock.fcstd]
2016-07-08 Updated project
    [nixie-clock.fcstd, nixie_clock.brd]
2016-07-13 Added new model on freecad model and updated pcb board
    [nixie-clock.fcstd, nixie_clock.brd, nixie_clock.sch]
2016-07-17 Updated project: new documentation & more ...
    [in82socket.stl, nixie-clock.fcstd, nixie_clock.brd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]
2016-07-25 Fixed some issues related with the multiplexed data
    [nixie_clock.brd, nixie_clock.sch]
2016-07-26 Updated clock.c and removed rencoder test
    [nixie_clock.brd, nixie_clock.sch]
2016-08-11 Fixed bug related to multiplexed data
    [nixie_clock.brd, nixie_clock.sch]
2016-10-12 Fixed CPU consumption with rotary encoder
    [clock.c]
2016-10-13 Fixed problem related with the elapsed time method
    [clock.c]
2016-10-16 Added countdown timer in relay
2017-05-15 freecad model updated
    [nixie-clock.fcstd, nixie_clock.brd, nixie_clock.sch]
2017-08-07 Fixed problem related with the pcb
    [nixie-clock.fcstd, nixie_clock.brd, nixie_clock.sch]

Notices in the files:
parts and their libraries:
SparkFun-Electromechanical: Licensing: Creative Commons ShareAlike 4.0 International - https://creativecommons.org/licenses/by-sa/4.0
